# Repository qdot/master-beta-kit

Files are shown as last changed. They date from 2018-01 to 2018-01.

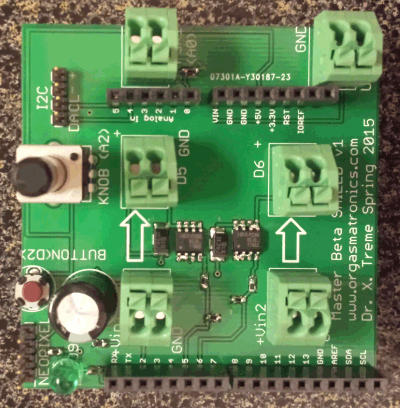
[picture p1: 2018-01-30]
images/board-image-1.png

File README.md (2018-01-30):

# Orgasmatronics Master Beta Kit

This repo is a fork of the Orgasmatronics Master Beta Kit. The files
hosted here have been released into the public domain, and are
available at the following website:

[http://www.photonsthesizeofyourballs.com/mbk/](http://www.photonsthesizeofyourballs.com/mbk/)

We've created a github repo for them, so they can be remixed, forked,
and passed around easily.

Thanks to all of the work of Dr. Xtreme and the Orgasmatronics team
for putting these together!

## Relevant Links

- [Original IndieGoGo campaign for the Master Beta Kit](https://www.indiegogo.com/projects/master-beta-kit-easy-erotic-engineering--2#/)
- [Youtube Video of Master Beta Kit Programming Instructions](https://www.youtube.com/watch?v=lAKY201O0bg)

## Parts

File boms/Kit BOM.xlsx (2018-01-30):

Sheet: basic kit
description | source | part number | number needed per unit | Individual cost | extended unit cost(1) | Unit Cost(10) | unit cost(100) | Unit cost(1000)
basic master beta board | China |  | 1 | $15.00
Arduino UNO R3 board | Sparkfun |  | 1 | $25.00 | $25.00 | $23.00 | $20.00
USB A to B cable, 6' | amazon |  | 1
AA battery holder with switch | digikey |  | 1
bullet vibe | china |  | 1
AA batteries | digikey |  | 2
male pigtail | amazon |  | 1
female pigtail | amazon |  | 1
9v connector | digikey |  | 1
bubblemailer | Uline |  | 1
foam to protect pins | ? |  | 1
labor to do shipping | XTO |  | 1
shipping cost | shpping easy |  | 1 | $5.00

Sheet: superdelux kit
description | source | part number | number needed per unit | Individual cost | extended unit cost(1) | Unit Cost(10) | unit cost(100) | Unit cost(1000)
basic master beta board | China |  | 1 | $15.00
Arduino UNO R3 board | Sparkfun |  | 1 | $25.00 | $25.00 | $23.00 | $20.00
USB A to B cable, 6' | amazon |  | 1 | $3.00
AA battery holder with switch | digikey |  | 1 | $4.00
bullet vibe | china |  | 2 | $1.00
AA batteries | digikey |  | 2 | $1.00
male pigtail | amazon |  | 2
female pigtail | amazon |  | 2
9v connector | digikey |  | 1 | $1.00
bubblemailer | Uline |  | 1
foam to protect pins | ? |  | 1
labor to do shipping | XTO |  | 1
shipping cost | shpping easy |  | 1
jumper wires |  |  | 4 | $50.00
FSR | sparkfun
3d printed FSR holder | cnc?
3d printer FSR holder mold inverse | cnc?
neopixel array | adafruit
header for neopixel array | samtec
cable for neopixel array | samtec
pressure sense board | china
header for pressure sense board | samtec
aluminum pressure adapter | china
labor to assemble pressure sense unit | xto
cable for pressure sense unit | samtec
hose for pressure sense unit | xto
ambrosia dildo | china/xto
vaginal/anal squeeze bulb | china/xto
cable from FSR | seraphim
x2 | XTO
x2 power supply wall wort | xto/seraphim
wifi sheild

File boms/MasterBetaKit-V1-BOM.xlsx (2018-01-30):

REFDES | Value | QTY | Manufacturer | Manufacturer Part Number | Digikey Part Number | package | Price
Q1 | IRF7862 | 2 | International Rectifier | IRF7862TRPBF | IRF7862TRPBFCT-ND |  | $0.75
Q2 | IRF7862 |  | International Rectifier | IRF7862TRPBF | IRF7862TRPBFCT-ND |  | $0.75
D1 | S1b | 2 | Fairchild Semiconductor | S1B | S1BFSCT-ND | DO-214AC | $0.13
D2 | S1b |  | Fairchild Semiconductor | S1B | S1BFSCT-ND | DO-214AC | $0.13
R1 | 10k | 5 | Panasonic Electronic Components | ERJ-3EKF1002V | P10.0KHCT-ND |  | $0.01
R2 | 10k |  | Panasonic Electronic Components | ERJ-3EKF1002V | P10.0KHCT-ND |  | $0.01
R3 | 10k |  | Panasonic Electronic Components | ERJ-3EKF1002V | P10.0KHCT-ND |  | $0.01
R4 | 10k |  | Panasonic Electronic Components | ERJ-3EKF1002V | P10.0KHCT-ND |  | $0.01
R5 | 10k |  | Panasonic Electronic Components | ERJ-3EKF1002V | P10.0KHCT-ND |  | $0.01
R6 | 3.3k | 1 | Panasonic Electronic Components | ERJ-3EKF3301V | P3.30KHCT-ND |  | $0.01
R7 | 1k | 1 | Panasonic Electronic Components | ERJ-3EKF1001V | P1.00KHCT-ND |  | $0.01
R8 | 330 | 1 | Panasonic Electronic Components | ERJ-3EKF3300V | P330HCT-ND |  | $0.01
R9 | 20k Pot | 1 | Bourns | PTV09A-4030U-B203 | PTV09A-4030U-B203-ND |  | $0.60
C1 | 1000 uF, 6.3 V | 1 | Kemet | ESH108M6R3AH1AA | 399-6558-ND |  | $0.13
LED1 | green | 1 | KingBright | WP7113GT | 754-1731-ND |  | $0.08
X1 | spring contact | 6 | Phoenix Contact | 1984963 | 277-6354-ND |  | $0.25
X2 |  |  | Phoenix Contact | 1984963 | 277-6354-ND |  | $0.25
X3 |  |  | Phoenix Contact | 1984963 | 277-6354-ND |  | $0.25
X4 |  |  | Phoenix Contact | 1984963 | 277-6354-ND |  | $0.25
X5 |  |  | Phoenix Contact | 1984963 | 277-6354-ND |  | $0.25
X6 |  |  | Phoenix Contact | 1984963 | 277-6354-ND |  | $0.25
SW1 | button | 1 | Panasonic | EVQ-11U05R | P8083SCT-ND |  | $0.20
J1 | 4 pin header | 1 | Samtec | TSW-104-14-G-S |  |  | $0.25
J2 | 4 pin header | 1 | Samtec | TSW-104-14-G-S |  |  | $0.25
J3 | UNO socket header 10 pin | 1 | samtec | SSQ-110-03-G-S |  |  | $1.39
J4 | UNO socket header 8 pin | 2 | samtec | SSQ-108-03-G-S |  |  | $1.12
J5 | UNO socket header 8 pin |  | samtec | SSQ-108-03-G-S |  |  | $1.12
J6 | UNO socket header 6 pin | 1 | samtec | SSQ-106-03-G-S |  |  | $0.84
total |  |  |  |  |  |  | $9.32

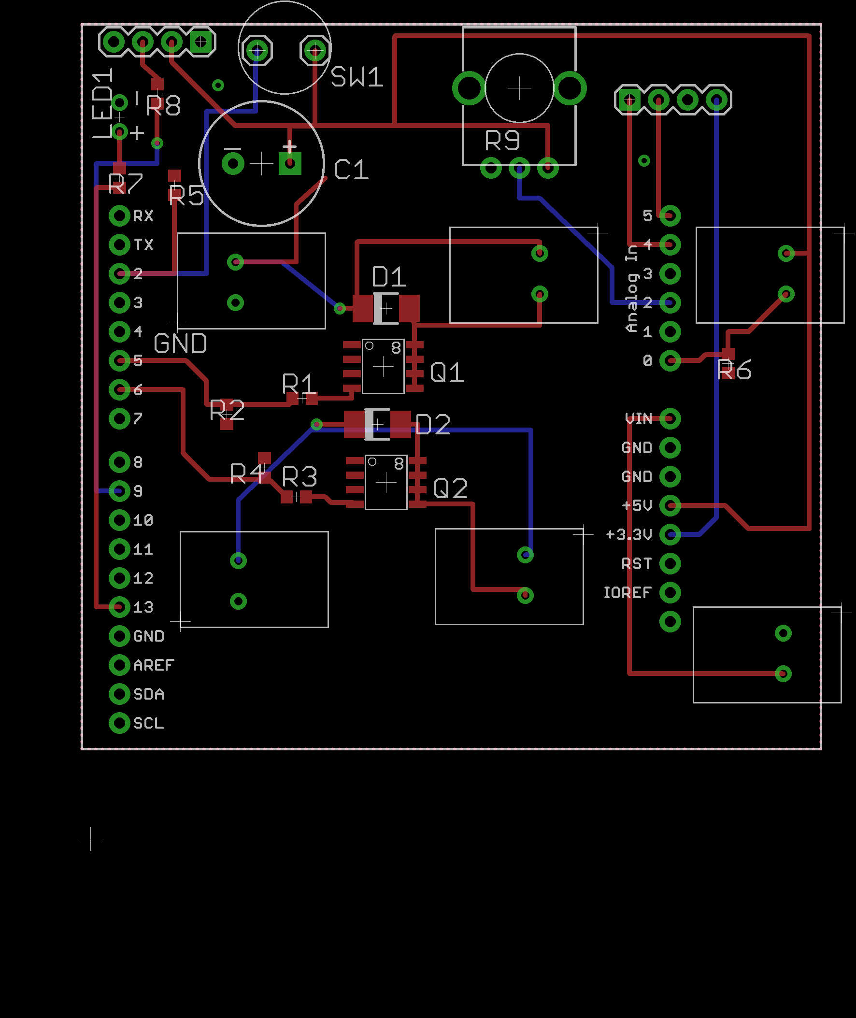
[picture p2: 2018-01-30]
images/component-position-image.png

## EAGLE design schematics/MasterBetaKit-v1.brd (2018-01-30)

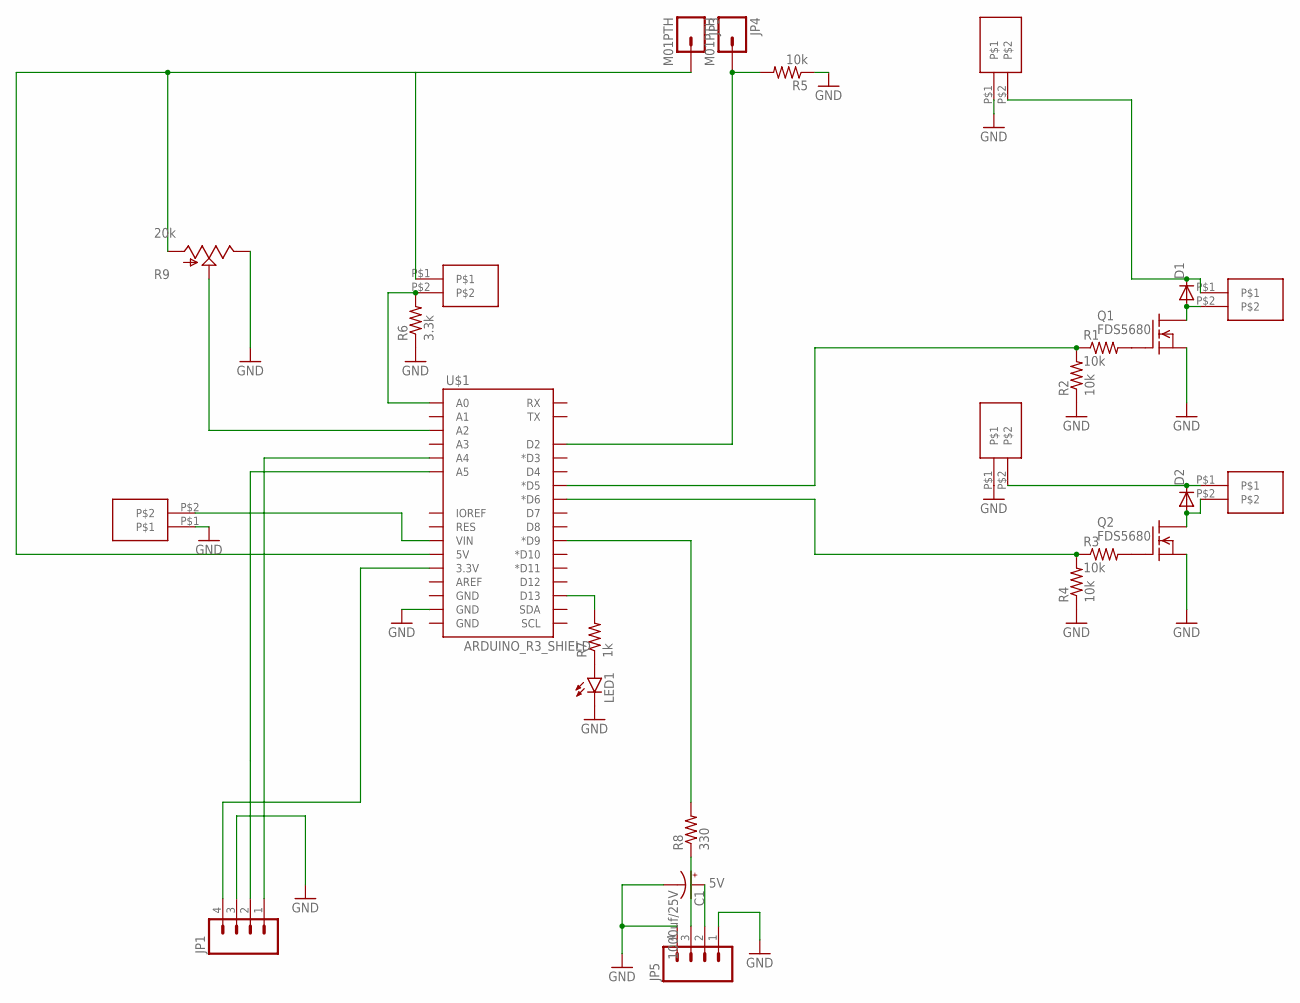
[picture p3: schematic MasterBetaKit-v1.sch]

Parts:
C1: 1000uf/25V; CPOL-RADIAL-1000UF-25V-KIT
D1, D2: DIODE-DO-214AC; DO-214AC
JP1, JP5: M04PTH; 1X04
JP3, JP4: M01PTH; 1X01
LED1: LED-3MM-NO_SILK; LED3MM-NS
Q1, Q2: FDS5680; SO-8
R1, R2, R3, R4, R5: 10k; R0603
R6: 3.3k; R0603
R7: 1k; R0603
R8: 330; R0603
R9: 20k; ALPS_POT_KIT
U$1: ARDUINO_R3_SHIELD; UNO_R3_SHIELD
U$3, U$6: SPRING-TERMINAL
X1, X2, X3, X5: SPRING-TERMINAL

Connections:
5V: C1.+, JP3.1, JP5.2, R9.P$3 (A), U$1.5V, X2.P$1
BUTTON: JP4.1, R5.2, U$1.D2
CL: JP1.2, U$1.A5
DA: JP1.1, U$1.A4
GND: C1.-, JP1.3, JP5.1, JP5.4, LED1.K (C), Q1.1 (S), Q1.2 (S), Q1.3 (S), Q2.1 (S), Q2.2 (S), Q2.3 (S), R2.1, R4.1, R5.1, R6.1, R9.P$1 (E), U$1.GND@1 (GND), U$3.P$1, X1.P$1, X3.P$1
unnamed: R1.1, R2.2, U$1.D5 (*D5)
unnamed: R8.2, U$1.D9 (*D9)
unnamed: Q1.4 (G), R1.2
unnamed: D1.A, Q1.5 (D), Q1.6 (D), Q1.7 (D), Q1.8 (D), U$6.P$2
unnamed: Q2.4 (G), R3.2
unnamed: D2.A, Q2.5 (D), Q2.6 (D), Q2.7 (D), Q2.8 (D), X5.P$2
unnamed: R3.1, R4.2, U$1.D6 (*D6)
unnamed: R6.2, U$1.A0, X2.P$2
unnamed: JP5.3, R8.1
unnamed: LED1.A, R7.1
unnamed: R7.2, U$1.D13
unnamed: R9.P$2 (S), U$1.A2
unnamed: U$1.VIN, X1.P$2
VCC: JP1.4, U$1.3.3V
X4: D1.C, U$6.P$1, X3.P$2
X6: D2.C, U$3.P$2, X5.P$1

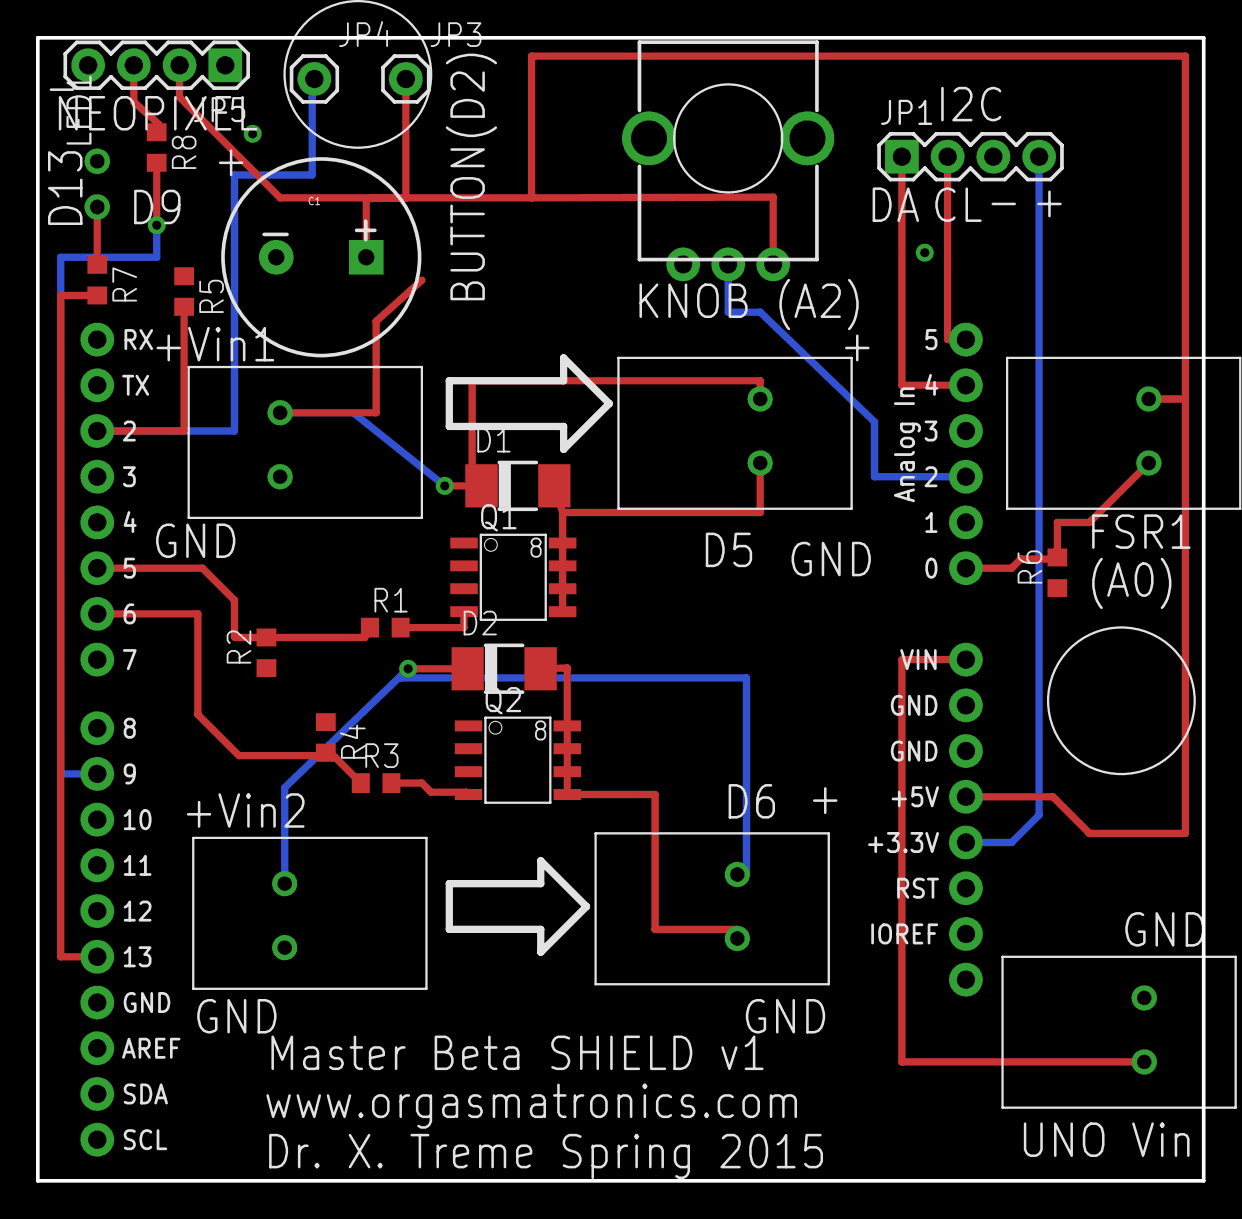
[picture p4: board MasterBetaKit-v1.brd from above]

Board: 2 copper layers, 64.8 x 63.5 mm, 26 parts (0 on the bottom side), 21 nets.

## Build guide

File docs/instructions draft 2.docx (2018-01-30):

1. Make sure you have all the parts of the kit: Arduino UNO R3, USB cable(A to B, just like a printer cable), Master Beta Shield, bullet vibrator with wires stripped(it should come stripped), 2 AA batteries in AA battery holder, a computer running any type of windows, mac OS, or linux
  a. Photo of uno in box
  b. Photo of uno out of box
  c. Photo of USB cable showing both ends clearly
  d. Photo of master beta shield board
  e. Photo of bullet vibrator with wires stripped
  f. Photo of AA batteries inside the holder with lid off
  g. Photo of AA battery holder with lid on, with on/off switch called out in a label on the picture
  h. Photo of computer, showing USB port with a label on photo
2. Go to the website www.arduino.cc and click on download, or go directly to http://arduino.cc/en/Main/Software . Based on what operating system you have, click on the link on the right with the appropriate installer. Follow the instructions as they pop up to install the software. This website will be a great resource for you as you explore Arduino. There are many useful website out there, including www.sparkfun.com and www.adafruit.com and hopefully ours(www.orgasmatronics.com/arduino [add this?]), but the main site is always a key resource for figuring out software issues and what is out there in new hardware. Once you have the Arduino software installed, open it up so that you can see the main screen on your computer.
3. Take the Arduino UNO R3 out of its box and plug the USB cable into both your computer and the Arduino UNO. The wider and flatter connector connects to your computer and the more square shaped connector connects to the Arduino(just like a printer connection).
4. In the Arduino software, first click on “tools”, then go down to “board”, and make sure there is a check mark next to “Arduino UNO”. “Arduino UNO” should also appear next to the word “board” in the pulldown menu. If that is not the case, go to the menu of boards and select the “Arduino UNO” that that it is.
  a. Screenshot of this menu all the way out, with markings on figure showing where the checkmark goes for UNO
5. In the Arduino software, on the “file” menu, pull down to examples, then basics, then “blink”, then click on blink.
  a. Show screen shot here of how that menu opens up
6. Click on the arrow pointing to the right to upload and compile this program. This should then show some status reports for a few seconds and then say “uploaded to board”. If you see error messages(which are generally in an amber font color), you may want to unplug and replug the board, shut down and restart the arduino software, or change the serial port in the tools pulldown menu. Also see further troubleshooting guides on the Arduino site. If it does work, you should now see a blinking light on your board. Congratulations!! This is your first working Arduino program! You have now made software control the hardware!!!
7. Now go in the code for the blink program and in the code that is as follows:

void loop() {

digitalWrite(led, HIGH); // turn the LED on (HIGH is the voltage level)

delay(1000); // wait for a second

digitalWrite(led, LOW); // turn the LED off by making the voltage LOW

delay(1000); // wait for a second

}

Delay() is a function that makes the arduino wait for a certain number of miliseconds(thousanths of a second). So 1000 miliseconds is 1 second, and this loop program flashes the on state (HIGH) for 1 second and the off state (LOW) for one second. Now edit it to be different wait times, say 100 and 100 instead of 1000 and 1000 or 2000 and 150, or whatever. This function(delay) is extremely important in all the things we will do here. The Arduino runs at a clock speed of 16 MHz, meaning it can do 16 million things in a second. In practical robotics and sex toy projects you probably never want to do more than about 10 things in a second. Maybe 20 or 50, but not more than 100! What do I mean by “things”? turning anything on, off, or whatever. So in order to make the Arduino do things at a human time scale we always need to be tweaking these delays, and miliseconds are the right unit because we generally want to wait less than 1 second but more than 1/1000th of a second. So now you have mastered control of the Arduino’s relationship with time, which basically makes you a time lord!

8. Now plug the vibrator wires into the spring clips on the top output line
  a. Show photograph showing the correct clip to use
  b. Show photograph zoomed in of the stripped wires with caption: note that the stripped parts must be in contact with the spring clips inside in order for electricity to flow.
  c. Show detail of a finger pushing down on the spring clip while a person’s other hand puts one of the vibrator wires into the hole of the spring clip. It takes some force to get the spring clip to open up, and you push down on the tab to make that happen. When the wire is as far in as it will go, release the tab, and it should be gripped by considerable friction in the spring clip.
  d. Photograph of both wires in, with hand tugging gently on the wire to make sure it is properly fixed in there. Caption: note that a gentle tug is a good way to check that the wires are properly situated.
9. Plug the AA battery pack into the input power supply
  a. Show a photograph of the battery pack, with labels showing where the switch is, and marking red as plus and black as minus.
  b. A photograph shows where the input is on the board for this power supply, and shows where it’s marked as being digital pin 5 output.
  c. Following the same procedure as for the vibrator, put the wires in the spring clips, making sure red and black go to the correct terminals. Show photo of correct orientation of wires.
  d. Open the program from the X. Treme tutorial fademotor1.ino, and upload it to the arduino board exactly as in the previous example.
  e. Make sure that if it is not already, the switch is in the “on” position(see above photo)
  f. You programmed a vibrator!! With power over a motor, you can now build ALL OF THE ROBOTS. But you won’t because you’ve seen Terminator 2 and know that will quickly lead to Judgment Day. So you proceed to the next step here and build the next sex toy project.
  g. Again, if you look at the code you see the use of the delay() function. Right now it’s 30 milliseconds, or 0.03 seconds, about 1/30th of a second. If you edit the line delay(30) to be, say, delay(15), it will be half the delay which makes it twice as fast. Try it! Note that like several computer languages, each line has to end in a semicolon or the whole thing will fail in any of various ways. So always keep that semicolon! Also, anything after a double “/” is a “comment”, meaning that is English for other humans to read and is not read by the machine. When you change stuff, comment it, that’s what real coders do and is one reason physicist code makes people sad (we tend to have horrific documentation and commenting). For more information on the Arduino’s language, see the reference page at http://arduino.cc/en/Reference/HomePage . It’s almost identical to the language called “Processing”, which is documented here: https://processing.org. If you want to build programs where both your computer and the arduino do something interesting, processing is a great place to start, but I’m going to skip that in this tutorial(partly because a lot of fun stuff with processing and vibrators can infringe on certain people’s troll-ass bullshit patents, but mostly because I’m lazy).
10. Open the file knob_motor_speed_simple.ino in the Arduino software and upload it to the arduino. Again, make sure the switch on the AA battery pack is in the “on” position. Now turn the knob on the board(see photo showing knob). You have a speed controller! How does this work? The knob is what is called a potentiometer(http://en.wikipedia.org/wiki/Potentiometer), colloquially known as a “pot”, which changes the relative position of the middle connection to the two outer ones as you turn the knob. This changes the voltage that goes into an analog input, which is what the code reads(see the code comments for details). If you look at the comments in the code one thing to notice is that inputs are scaled to 1023 and outputs to 255. That is because 2 to the power of 10 is 1024 and 2 to the power of 8 is 256. So a 10 bit input scales to 1023(or 1111111111 in binary) and a 8 bit output scales to 255( or 11111111 in binary). This is not that important exactly but if you want to play with this code yourself you have to be aware of it because these scaling factors have to be carefully dealt with or you end up with crazy numbers.
11. Now open the program button_simple.ino in the Arduino software, and upload it to the Arduino board. Again, be sure the AA battery pack is turned “on”. Now push the button(see photograph of button). Buzz, buzz!! This button is simply connecting a digital input line that is naturally in a zero voltage state with +5V, making it a digital “ON”, and the code detects that and turns the vibrator on.
12. Now open the program sawtooth_knob.ino in the Arduino software and upload it to the board. This program is a simple “sawtooth wave”, so it ramps up, then abruptly drops to zero, then ramps up again, and so on, unlike the earlier triangle wave that ramps up then ramps back down at the same rate. Now turn the knob. You can change the rate! Unlike a lot of patterns, this might actually be useful/fun! But there’s more…
13. Open the program sawtooth_knob_button.ino and load it. This is the same as the previous program only when it reaches the max it just stays there until the button is pressed, which resets it. You can control the ramp time with the knob. Read the comments in the code to see how it works. Again, we’ve made an actual useful toy here! This is a sort of tease, where the user can get close to climax, then reset and repeat, ramping slower and slower.
14. More stuff! You can try the chaos code, and play with that, for endless mathematical/physics fun. Also a 9V battery and battery leads(not included) can let you make the thing self-contained without the USB. Duct tape that whole puppy together and you’ve got a crude but effective controller that you can actually use in the bedroom! For even more, see advanced tutorials on how to use the other features of this board. You can do a ton of things with it! You can control the x1 orgasmatron, various wand or bullet products, valves to control pouring of liquids, LED arrays, and can take input from force and pressure sensors! All of that is for more advanced tutorials however, and it makes sense to truncate this here and save that for future tutorials. The point of this kit is, after all, to introduce beginners. Those with lots of experience can figure out how to use the other features by looking at the Eagle files for the board.

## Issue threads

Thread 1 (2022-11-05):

Vibrator always 100% power

arduino-woman, 2022-11-05:
Just got a Master Beta kit, and everything seems to be setup correctly, in theory. Turning on the AA battery pack makes the vibrator turn on to 100% full power.

But after successfully uploading any code to the Arduino, I switch the AA battery pack on, and the vibrator still only ever goes on to 100% full power, no matter what code I upload. What am I missing? Thank you!

qdot, 2022-11-05:
This is not actually my project, I just archived it here. I've never built it and can't tell you how anything works.

You might want to try a DIY community like KinkyMakers: https://kinkymakers.com

Closed 2022-11-05.

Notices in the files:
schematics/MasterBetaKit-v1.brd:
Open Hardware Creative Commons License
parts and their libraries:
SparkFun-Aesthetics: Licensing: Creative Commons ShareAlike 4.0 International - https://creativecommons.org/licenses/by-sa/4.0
